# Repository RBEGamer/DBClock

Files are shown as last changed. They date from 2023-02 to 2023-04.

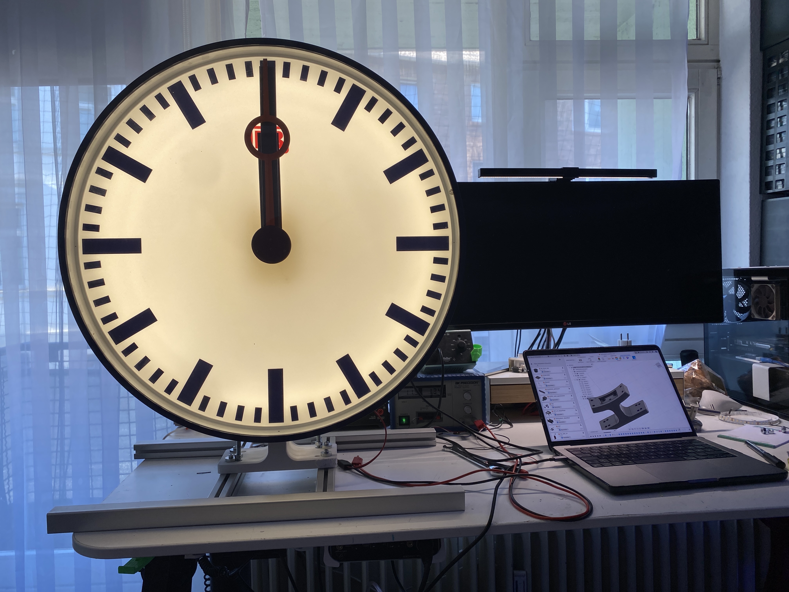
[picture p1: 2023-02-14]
documentation/images/2023-02-14 13.25.36.jpg

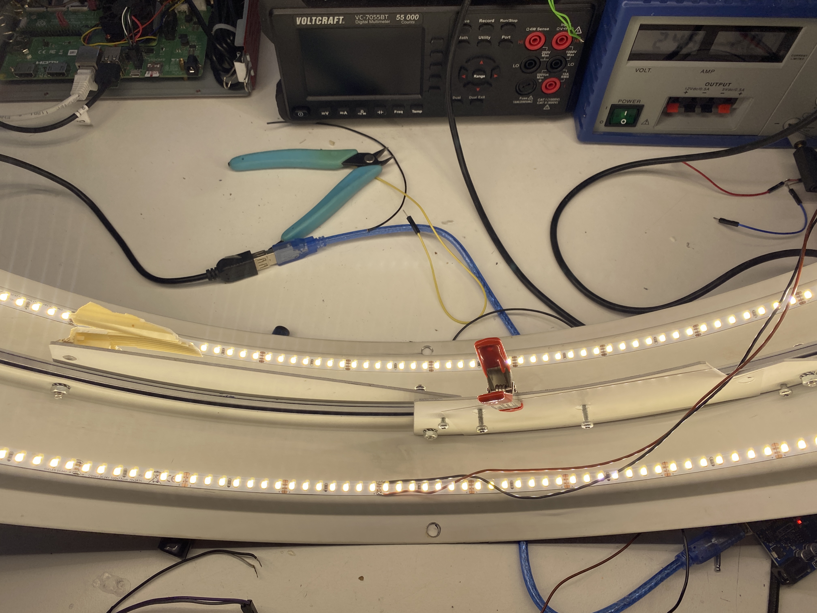
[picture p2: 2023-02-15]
documentation/images/2023-02-13 15.05.31.jpg

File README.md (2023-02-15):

# DBClock

final_clock

## Features

* NTP Sync
* LED lightning, dimmable
* Stand
* 12V 
* Webinterface for configuration
* Daylight Saving

## Bahnhofsuhr-DB

[bahnhofsuhr-db-shop](https://bahnshop.de/db-originale/sonstiges/1749/bahnhofsuhr-db)

Dark blue metal case, acrylic glass panes, dial white,with black hour and minute markers, red hole second hand, red DB logo unlit.

Condition: used, in new design, the sale is in the current condition as a decorative object, a function can not be guaranteed, rust spots, paint chips and scratches in the glass and paint are part of the character. The holder is not included in the delivery. The article picture is an exemplary representation.

Dimensions: 60 cm diameter
Weight: approx. 30 kg

Shipping is by freight forwarding on one-way pallet (free curbside). Disposal of the pallet is done by the customer.

In my clock, `BU 190t S230` the clock-drives were used.

### MORE LINKS

* [PROFILINE-Analoguhr.pdf]([https://bahnshop.de/db-originale/sonstiges/1749/bahnhofsuhr-db](https://www.mobatime.com/wp-content/uploads/2021/11/LD-800078.24-PROFILINE-Analoguhr.pdf))

## BU 190t S230

A complete manual for the drive can be found on the manufacturers website:
[Uhrwerk-BU-190-230-Installation.pdf](https://www.buerk-mobatime.de/wp-content/uploads/2020/01/BD-800603.01-Uhrwerk-BU-190-230-Installation.pdf)

### POWER THE DRIVE



I got the `BU 190t S230` version which needs 230v.
After a teardown, a small rectifier is found so that the drive uses a lower voltage for the motors and logic.
After further investigation on the transformers, the drive is internally operated with 12 V. 
So if you solder some wires directly to the rectifier and run it with a 12 V power supply, the drive works fine.
It also uses its own crystal, so no need for a stable 60Hz sync from the mains.

### SET THE TIME USING AN ARDUINO

In general it is simple to set the clock using a serial connection to the `IN` connector of the drive.
The connector is a `RJ12` jack it is connected to the Arduino using the following pins.

| Arduino | BU 190t | RJ12 pin |
|---|---|---|
| TX | TTL IN (RxD) | 1 |
| GND | GND | 2 |

The following Arduino code function sends the current time to the drive.
After running the code, the clockdrive syncs up.
This takes up the 6 minutes.

```c++
void send_time_to_clock(const uint8_t _h, const uint8_t _m, const uint8_t _s, bool _signal_ok = true);

void setup(){
  // NOTE THE SPEICAL SERIAL INIT ACCORDING THE DRIVES DATASHEET
  Serial.begin(9600,SERIAL_7E1);
}

void loop(){

send_time_to_clock(13,14,15)
//SEND THE CURRENT TIME EACH SECOND
// USE A DEDICATED TIMER FOR THIS
delay(1000); 
}
void send_time_to_clock(const uint8_t _h, const uint8_t _m, const uint8_t _s, bool _signal_ok = true){
  const uint8_t sec = max(_s, 60);
  String s = String(sec);
  if(sec<10){
    s="0"+s;
  }

  const uint8_t min = max(_m, 60);
  String m = String(min);
  if(min<10){
    m="0"+m;
  }

  const uint8_t hour = max(_h, 24);
  String h = String(hour);
  if(hour<10){
    h="0"+h;
  }

  String signok = "M";
  if(_signal_ok){
    signok = "A";
  }
  // USE WITH IN SETUP Serial.begin(9600,SERIAL_7E1);
  //DATE SET TO 10.10.2000 => NOT NEEDED HERE
  Serial.print("O" + signok + "L010100F"+ h + m + s +"\r");
}
```

In my case i used a Arduino Mega, with more than one hardware serial interface.
The desing is using `Serial2` for the clock drive and `Serial` to communicate with the PC or ESP8266 for NTP Sync.
By using a RTC like the `DS3231` in combination with the `ESP8266` for NTP sync, you get a very stable self syncing clock!
The the `src` directory for the Arduino and `ESP866` sources.

 Arduino

## LED

led

* [IRF520 MOSFET Treiber Modul](https://de.aliexpress.com/item/32667789271.html)
* [LED-Streifen 5m weiß](https://www.ledpoint.it/de/led-streifen-5m-warm-weiß-3500k-3step-2835-120ledm-12v-144wm)

The old lamp was replaced with a neutral-white 12B led strip with 144 LEDs/m.
Using a mosfet connected to the Arduino PWM GPIO `Pin 8`, so it is possible to control the strip using software.
The current implementation, allows fade up/down on predefined times, on/off from 0-100%.

### BUTTON

A pushbutton from `GND` to Arduino GPIO `2` can be connected to set the LED intensity modes manually.

## FINAL PINOUT

| Arduino | BU 190t RJ12 pin | DS3131 | PUSHBUTTON PIN | MOSFET PIN | ESP8266 |
|---|---|---|---|---|---|
| VIN | + pin on fullbridge | | | | |
| TX | TTL IN (RxD)  1 | | | | |
| GND | GND 2 | GND |  1 | GND | GND |
| 2 | | |  2 | | |
| 8 | | | | SIG | |
| 5V | | VCC | | VCC | VIN |
| RX | | | | | TX |
| SDA | | SDA | | | |
| SCL | | SCL | | | |

## Stand

stand

A clock stand/holder was not included, so a simple millable (or 3d printable ABS 100% infill) was designed.
The bottom holes are designed to be mounted on 30x30 n-nut profiles.
The files can be found in the `src/3d_print/clock_mount` directory.

Four `M8x30` with lock nuts were used to attach the clock to the milled stand.

**NOTE** The clock weighs about 30 kg, so the stand should be durable...

## PICTURES



### CLOCK FINGERS


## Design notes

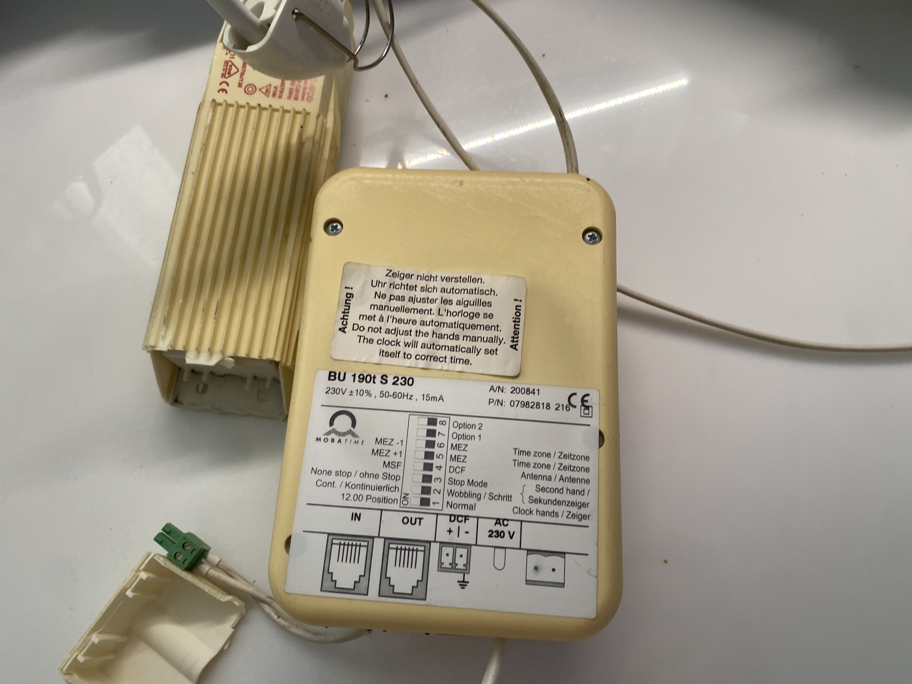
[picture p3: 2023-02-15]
documentation/images/2023-02-08 12.05.26.jpg

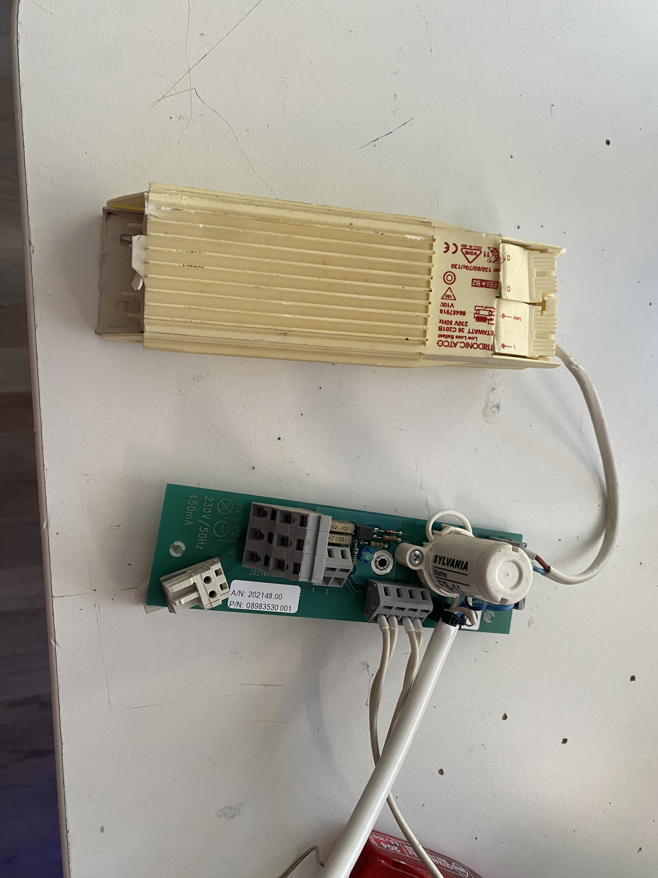
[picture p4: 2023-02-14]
documentation/images/2023-02-08 12.06.29.jpg

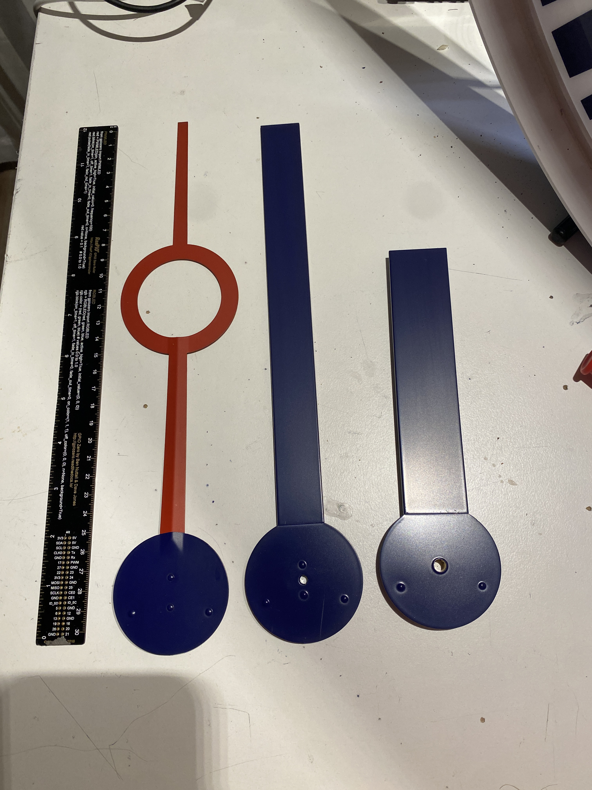
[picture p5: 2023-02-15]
documentation/images/2023-02-12 22.24.04.jpg

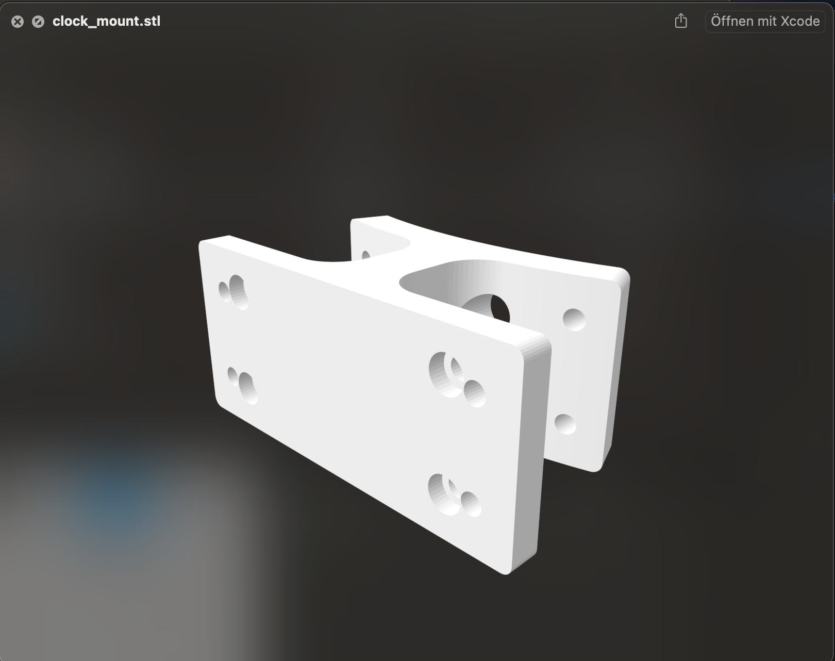
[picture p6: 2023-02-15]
documentation/images/stand.png

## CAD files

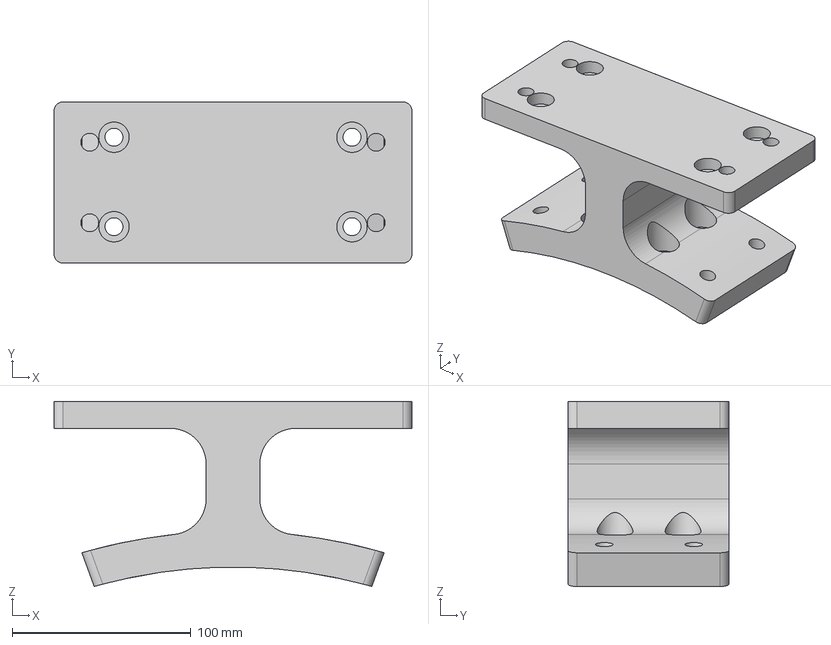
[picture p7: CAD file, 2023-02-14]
src/3d_print/clock_mount/clock_mount.step
200.0 x 90.0 x 103.4 mm

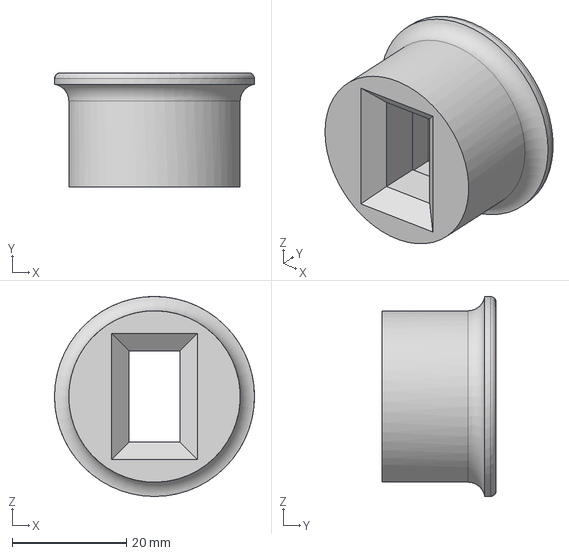
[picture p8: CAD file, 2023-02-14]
src/3d_print/usb_cable_mount/usb_cable_mount.step
35.0 x 20.0 x 35.0 mm

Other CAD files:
src/3d_print/clock_mount/clock_mount.f3d
src/3d_print/clock_mount/clock_mount.stl
src/3d_print/usb_cable_mount/usb_cable_mount.f3d
src/3d_print/usb_cable_mount/usb_cable_mount.stl

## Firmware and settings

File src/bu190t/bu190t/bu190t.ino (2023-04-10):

#define DS1307_CTRL_ID 0x68  //I2C ADDRESS OF DS3231 OR DS1307
#define EEPROM_INDEX_LED_MODE 0
#define EEPROM_INDEX_DLS 1
#define RTC_TIMEZONE 0 //0=UTC ,1=MEZ
#define VERSION "2.0.0"
#define WIFIEXTENTION_SERIAL Serial3 // TO ESP8266
#define CLOCK_SERIAL Serial2
#define DEBUG_SERIAL Serial //USB
#define LIGHTMODE_AUTO_HOUR_START 20
#define LIGHTMODE_AUTO_HOUR_END 23
#define LIGHTMODE_AUTO_HOUR_MAX_PWM 100

#include <EEPROM.h>
#include <Wire.h>
#include "RTClib.h"


void send_status(const String _command, const String _payload);
void update_according_led_mode(const uint8_t _led_mode);
void send_time_to_clock(const int _h, const int _m, const int _s, bool _signal_ok = true);
uint16_t crc16(const String _data, const uint16_t _poly = 0x8408);
bool check_for_i2c_device(const uint8_t _addr);
bool summertime_eu(const int _year, const signed char _month, const signed char _day, const signed char _hour);
String getValue(const String data, const char separator, const int index);

int clock_hour = 0;
int clock_min = 0;
int clock_sec = 0;

const uint8_t PIN_BUTTON_BRGHT = 2;
const uint8_t PIN_LED_PWM = 8;
const long CLOCK_UPDATE_INTERAL = 1000;


unsigned long previousMillis = 0;
uint8_t current_led_pwm = 0; // to fade from 0-255
uint8_t target_led_pwm = 0;
bool last_brght_button_state = false;


String readString;
bool cmd_started = false;
#define CMD_START_CHARACTER '%'
#define CMD_SEPERATION_CHARACTER '_'
//EEPROM MANAGED VARIABLES
uint8_t led_mode = 0;
uint8_t daylightsaving_enabled = 0;


RTC_DS1307 rtc;

void setup() {
  // put your setup code here, to run once:
  DEBUG_SERIAL.begin(9600);
  //IMPORTANT FOR THE BU 190t WATCH DRIVES
  CLOCK_SERIAL.begin(9600,SERIAL_7E1); // FIRST CLOCK DRIVE
  //FOR WIFI INTERFACE
  WIFIEXTENTION_SERIAL.begin(9600);
  // INIT PINS
  pinMode(PIN_BUTTON_BRGHT, INPUT_PULLUP);
  pinMode(PIN_LED_PWM, OUTPUT);
  analogWrite(PIN_LED_PWM, 0);

  //READ EEEPROM VALUES
  led_mode = EEPROM.read(EEPROM_INDEX_LED_MODE);
  daylightsaving_enabled = EEPROM.read(EEPROM_INDEX_DLS);

  update_according_led_mode(led_mode);
  //INIT I2C
  Wire.begin();
  //CHECK IF RTC IS PRESENT
  //SETUP TIME
  if(check_for_i2c_device(DS1307_CTRL_ID)){
    //CHECK IF RTC IS IN STOP MODE SO ONE INITIAL SET IS NEEDED
    // ITS NOT WORKING IF THE TIMLIB IS USED DIRECTLY
    if(rtc.begin()){
      if (!rtc.isrunning()) {
        Serial.println("RTC lost power, let's set the time!");
        rtc.adjust(DateTime(F(__DATE__), F(__TIME__)));
      }else{
        send_status("log", "RTC RUNNING");
        rtc.adjust(DateTime(F(__DATE__), F(__TIME__)));
      }
       
    }else{
      send_status("log", "!RtcChipPresent");
    }
    send_status("log", "RtcFound");
  }else{
    send_status("log", "RtcNotFound");
  }
  
  send_status("version", VERSION); 
  
}


String getValue(const String data, const char separator, const int index) {
  int found = 0;
  int strIndex[] = {
    0,
    -1
  };
  int maxIndex = data.length() - 1;
  for (int i = 0; i <= maxIndex && found <= index; i++) {
    if (data.charAt(i) == separator || i == maxIndex) {
      found++;
      strIndex[0] = strIndex[1] + 1;
      strIndex[1] = (i == maxIndex) ? i + 1 : i;
    }
  }
  return found > index ? data.substring(strIndex[0], strIndex[1]) : "";
}

void send_status(const String _command, const String _payload){
 DEBUG_SERIAL.println("%" + _command + "_" + _payload + "_" + crc16(_command + _payload));
 WIFIEXTENTION_SERIAL.println("%" + _command + "_" + _payload + "_" + crc16(_command + _payload));
}


bool check_for_i2c_device(const uint8_t _addr){
    Wire.beginTransmission(_addr);
    uint8_t error = Wire.endTransmission();
    if (error == 0) {
      return true;
    }
    return false;
}

// https://forum.arduino.cc/t/time-libary-sommerzeit-winterzeit/221884/2
// European Daylight Savings Time calculation by "jurs" for German Arduino Forum
// input parameters: "normal time" for year, month, day, hour and tzHours (0=UTC, 1=MEZ)
// return value: returns true during Daylight Saving Time, false otherwise
// #define RTC_TIMEZONE 0=UTC ,1=MEZ
bool summertime_eu(const int _year, const signed char _month, const signed char _day, const signed char _hour)
{
    if (_month < 3 || _month > 10)
    {
        return false; // keine Sommerzeit in Jan, Feb, Nov, Dez
    }
    else if (_month > 3 && _month < 10)
    {
        return true; // Sommerzeit in Apr, Mai, Jun, Jul, Aug, Sep
    }
    else if (_month == 3 && (_hour + 24 * _day) >= (1 + RTC_TIMEZONE + 24 * (31 - (5 * _year / 4 + 4) % 7)) || _month == 10 && (_hour + 24 * _day) < (1 + RTC_TIMEZONE + 24 * (31 - (5 * _year / 4 + 1) % 7)))
    {
        return true;
    }
    else
    {
        return false;
    }
}

uint16_t crc16(const String _data, const uint16_t _poly = 0x8408) {
  uint16_t crc = 0xFFFF;
  for (int i = 0; i < _data.length(); i++) {
    const uint8_t b = (byte)_data[i];
    uint8_t cur_byte = 0xFF & b;

    for (int it = 0; it < 8; it++) {
      if ((crc & 0x0001) ^ (cur_byte & 0x0001)) {
        crc = (crc >> 1) ^ _poly;
      } else {
        crc >>= 1;
      }
      cur_byte >>= 1;
    }
  }
  crc = (~crc & 0xFFFF);
  crc = (crc << 8) | ((crc >> 8) & 0xFF);
  return crc & 0xFFFF;
}


void send_time_to_clock(const int _h, const int _m, const int _s, bool _signal_ok = true){
  const int sec = _s%60;
  String s = String(sec);
  if(sec<10){
    s="0"+s;
  }

  const int min = _m%60;
  String m = String(min);
  if(min<10){
    m="0"+m;
  }

  const int hour = _h%24;
  String h = String(hour);
  if(hour<10){
    h="0"+h;
  }

  String signok = "M";
  if(_signal_ok){
    signok = "A";
  }
  // USE WITH Serial.begin(9600,SERIAL_7E1);
  CLOCK_SERIAL.print("O" + signok + "L230212F"+ h + m + s +"\r");
  //Serial3.print("O" + signok + "L230212F"+ h + m + s +"\r");
  send_status("ct", h + ":" + m + ":" + s);
}


void update_according_led_mode(const uint8_t _led_mode){
    const uint8_t led_mode = _led_mode % 7;
    if(led_mode == 0){
      target_led_pwm = 0;
    }else if(led_mode == 1){
      target_led_pwm = 20;
    }else if(led_mode == 2){
      target_led_pwm = 50;
    }else if(led_mode == 3){
      target_led_pwm = 150;
    }else if(led_mode == 4){
      target_led_pwm = 200;
    }else if(led_mode == 5){
      target_led_pwm = 255;  
     }else if(led_mode == 6){
       target_led_pwm = 0;
       current_led_pwm = 20;//INDICATE CLOCK IS IN AUTO
      //AUTO
    }
}
  

// SET TIME
//SET DATE
// SET DLS
// SET BRIGHNESS target_led_pwm




void loop() {

  
  

  /// BUTTOM FOR LIGHTMODE TOGGLE
  if(digitalRead(PIN_BUTTON_BRGHT) == LOW && last_brght_button_state == true){
    last_brght_button_state = false;
    led_mode++;
    if(led_mode > 6){
      led_mode = 0;
    }
    
    send_status("log", "LedMode" + String(led_mode));
    //SAVE LED MODE
    EEPROM.write(EEPROM_INDEX_LED_MODE,led_mode);
    update_according_led_mode(led_mode);

    
  }else if(digitalRead(PIN_BUTTON_BRGHT) == HIGH){
    last_brght_button_state = true;
  }


  // SEND TIME TO CLOCK EVERY 1s
  const unsigned long currentMillis = millis();
  if (currentMillis - previousMillis >= CLOCK_UPDATE_INTERAL) {
    previousMillis = currentMillis;
    DEBUG_SERIAL.println(".");
      DateTime now = rtc.now();
      int h = now.hour();
      if (daylightsaving_enabled > 0 && !summertime_eu(now.year(), now.month(), now.day(), h))
      {
        signed char h = h - 1;
        if (h < 0)
        {
            h += 24;
        }
        h = h % 24;
      }
      //SEND TIME TO CLOCK-DRIVES
      send_time_to_clock(h, now.minute(),now.second(), true);

      //ALSO HANDLE LED MODE AUTO
      if(led_mode == 6){
        // FADE 0-max and max-0
        //light up 3times as fast as for light down
        if(h == LIGHTMODE_AUTO_HOUR_START){
          target_led_pwm = map(max(now.minute()*3, 60),0,60,0, LIGHTMODE_AUTO_HOUR_MAX_PWM);
        }else if(h == LIGHTMODE_AUTO_HOUR_END){
          target_led_pwm = map(now.minute(),0,60,LIGHTMODE_AUTO_HOUR_MAX_PWM, 0);
        }
      }
    

    if(target_led_pwm != current_led_pwm){
      send_status("led", String(target_led_pwm));
    }
  }
  
  // UPDATE LEDS WITH SOME RAMP UP/DOWN
  if(target_led_pwm < current_led_pwm){
    if(abs(target_led_pwm-current_led_pwm) > 20){
      current_led_pwm-= 3;      
    }else{
      current_led_pwm--;
    } 
    analogWrite(PIN_LED_PWM, current_led_pwm);

  }else if(target_led_pwm > current_led_pwm){
    if(abs(target_led_pwm-current_led_pwm) > 20){
      current_led_pwm+= 3;
    }else{
      current_led_pwm++;
    }
    analogWrite(PIN_LED_PWM, current_led_pwm);
  }


    while (WIFIEXTENTION_SERIAL.available()) {
      delay(30); //delay to allow buffer to fill
      if (WIFIEXTENTION_SERIAL.available() > 0) {
        const char c = WIFIEXTENTION_SERIAL.read(); //gets one byte from serial buffer  
        
        if (c == '\n') {
          WIFIEXTENTION_SERIAL.flush();
          cmd_started = false;
          readString += CMD_SEPERATION_CHARACTER;
          break;
        }else if(c == CMD_START_CHARACTER && !cmd_started){
          cmd_started = true;
          readString = "";
        }else if(cmd_started){
          readString += c; //makes the string readString
        }         
      }
    }

    if (readString.length() > 0) {
      
      const String cmd = getValue(readString, CMD_SEPERATION_CHARACTER, 0);
      const String cmd_value = getValue(readString, CMD_SEPERATION_CHARACTER, 1);
      //st
      //sd
      if(cmd == "sb" && cmd_value != ""){
        const int tmp = cmd_value.toInt();
        if(tmp >= 0 && tmp < 7){
            led_mode = tmp;
            EEPROM.write(EEPROM_INDEX_LED_MODE,led_mode);
            update_according_led_mode(led_mode);
            DEBUG_SERIAL.println(led_mode);
        }
      }else if(cmd == "dls" && cmd_value != ""){
        const int dlsi = cmd_value.toInt();
        if(dlsi >= 0 && dlsi < 2){
          daylightsaving_enabled = dlsi;
          EEPROM.write(EEPROM_INDEX_DLS, daylightsaving_enabled);
        }
      }else if(cmd == "st" && cmd_value != ""){ //SET TIME
        const String sth = getValue(cmd_value, ':', 0);
        const String stm = getValue(cmd_value, ':', 1);
        const String sts =  getValue(getValue(cmd_value, ':', 2), '_', 0);;
        
        if(sth != "" && stm != ""){
          const int ih = sth.toInt();
          const int im = stm.toInt();
          const int is = sts.toInt();
          
          if(ih >0 && ih < 24 && im >0 && im < 60 && is >0 && is < 60){
            DateTime now = rtc.now();
            rtc.adjust(DateTime(now.year(), now.month(), now.day(), ih, im, is));
          }
        }
        DEBUG_SERIAL.println(sth + "::" + stm + "::" + sts);
      }else if(cmd == "sd" && cmd_value != ""){ //SET DATE
        const String sdday = getValue(cmd_value, '.', 0);
        const String sdmonth = getValue(cmd_value, '.', 1);
        const String sdyear = getValue(getValue(cmd_value, '.', 2), '_', 0);
        
        if(sdday != "" && sdmonth != "" && sdyear != ""){
          const int iday = sdday.toInt();
          const int imonth = sdmonth.toInt();
          const int iyear = sdyear.toInt();
          
          if(iday > 0 && iday < 31 && imonth >0 && imonth < 12){
            DateTime now = rtc.now();
            rtc.adjust(DateTime(iyear, imonth, iday, now.hour(), now.minute(), now.second()));
          }
        }
        DEBUG_SERIAL.println(sdday + ".." + sdmonth + ".." + sdyear);
      }

      send_status("gotcmd", cmd + "-"+cmd_value+"-");
      readString = "";
    } 

  delay(10);
}

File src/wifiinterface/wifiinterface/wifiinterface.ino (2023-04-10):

#define VERSION "3.2.1"
// ENABLE ON ESP8266-01 !!!!!!!!!!!!!!!!!!!!!!!!!!
#define USE_LITTLEFS
//FOR ESP8266-01
#define LED_BUILTIN 2

#include <Arduino.h>
#include "FS.h"

#ifdef ESP8266
#include <ESP8266WiFi.h>
#include <ESP8266WebServer.h>
#include <ESP8266mDNS.h>
#endif

#ifdef ESP32
#include <WebServer.h>
#define FORMAT_SPIFFS_IF_FAILED true
#ifdef USE_LITTLEFS
#define SPIFFS LITTLEFS
#include <LITTLEFS.h>
#else
#include <SPIFFS.h>
#endif
#include <ESPmDNS.h>
#endif



#include <WiFiClient.h>
#include <WiFiUdp.h>
#include <TimeLib.h>
#include <NTPClient.h>
#include <WiFiManager.h>
#include <WiFiUdp.h>
#include <ArduinoOTA.h>


// CONFIG -------------------------------------
#define WEBSERVER_PORT 80                                     // set the port for the webserver eg 80 8080
#define MDNS_NAME "dbclock"                                 // set hostname
#define WEBSITE_TITLE "DB Wifi Module Configuration"  // name your device
#define SERIAL_BAUD_RATE 9600
#define NTP_SEND_TIME_INTERVAL 60*60  //sende zeit an uhr all x minuten
#define DEFAULT_NTP_SERVER "pool.ntp.org"
#define DEFAULT_TIMEZONE 1
// END CONFIG ---------------------------------




String time_last = "not synced";
long last = 0;
long last_ee = 0;
#if defined(ESP8266)
const String BOARD_INFO = "DBCLOCKWIFIMODULE_FW_" + String(VERSION) + "_BOARD_" + "ESP8266";
#elif defined(ESP32)
const String BOARD_INFO = "DBCLOCKWIFIMODULE_FW_" + String(VERSION) + "_BOARD_" + "ESP32";
#endif
bool ntp_force_update = true;

const String ap_name = "DBClockConfiguration";

// END NEOPIXEL CONF ---------------------------
//FILES FOR STORiNG CONFIGURATION DATA
const char* file_ntp_server = "/file.txt";
const char* file_timezone = "/timezone.txt";
//VARS

int timezone = 0;
String ntp_server_url = "pool.ntp.org";
String last_error = "";
int rtc_hours = 0;
int rtc_mins = 0;
int rtc_secs = 0;
int rtc_day = 1;
int rtc_month = 1;
int rtc_year = 2020;
int rtc_hours_tmp = 0;
//IS SET TO TRUE IN SETUP IF A RTC CLOCK IS DETECTED
//USEDE FOR SOFTWARE CLOCK
unsigned long timeNow = 0;
unsigned long timeLast = 0;


// INSTANCES --------------------------------------------

#ifdef ESP8266
ESP8266WebServer server(WEBSERVER_PORT);
#endif

#ifdef ESP32
WebServer server(WEBSERVER_PORT);
#endif

WiFiUDP ntpUDP;
NTPClient timeClient(ntpUDP, DEFAULT_NTP_SERVER, 0, 60000);
WiFiClient espClient;
WiFiManager wifiManager;






const String phead_1 = "<!DOCTYPE html><html><head><title>";
const String phead_2 = "</title>"
                       "<meta http-equiv='content-type' content='text/html; charset=utf-8'>"
                       "<meta charset='utf-8'>"
                       "<link "
                       "href='http://ajax.googleapis.com/ajax/libs/jqueryui/1.8.16/themes/base/"
                       "jquery-ui.css' rel=stylesheet />"
                       "<script "
                       "src='http://ajax.googleapis.com/ajax/libs/jquery/1.6.4/jquery.min.js'></"
                       "script>"
                       "<script "
                       "src='http://ajax.googleapis.com/ajax/libs/jqueryui/1.8.16/"
                       "jquery-ui.min.js'></script>"
                       "<style>"
                       "html, body {"
                       "  background: #F2F2F2;"
                       " width: 100%;"
                       " height: 100%;"
                       " margin: 0px;"
                       " padding: 0px;"
                       " font-family: 'Verdana';"
                       " font-size: 16px;"
                       " color: #404040;"
                       " }"
                       "img {"
                       " border: 0px;"
                       "}"
                       "span.title {"
                       " display: block;"
                       " color: #000000;"
                       " font-size: 30px;"
                       "}"
                       "span.subtitle {"
                       " display: block;"
                       " color: #000000;"
                       " font-size: 20px;"
                       "}"
                       ".sidebar {"
                       " background: #FFFFFF;"
                       " width: 250px;"
                       " min-height: 100%;"
                       " height: 100%;"
                       " height: auto;"
                       " position: fixed;"
                       " top: 0px;"
                       " left: 0px;"
                       " border-right: 1px solid #D8D8D8;"
                       "}"
                       ".logo {"
                       " padding: 25px;"
                       " text-align: center;"
                       " border-bottom: 1px solid #D8D8D8;"
                       "}"
                       ".menu {"
                       " padding: 25px 0px 25px 0px;"
                       " border-bottom: 1px solid #D8D8D8;"
                       "}"
                       ".menu a {"
                       " padding: 15px 25px 15px 25px;"
                       " display: block;"
                       " color: #000000;"
                       " text-decoration: none;"
                       " transition: all 0.25s;"
                       "}"
                       ".menu a:hover {"
                       " background: #0088CC;"
                       " color: #FFFFFF;"
                       "}"
                       ".right {"
                       " margin-left: 250px;"
                       " padding: 50px;"
                       "}"
                       ".content {"
                       " background: #FFFFFF;"
                       " padding: 25px;"
                       " border-radius: 5px;"
                       " border: 1px solid #D8D8D8;"
                       "}"
                       "</style>";

const String pstart = "</head>"
                      "<body style='font-size:62.5%;'>"
                      "<div class='sidebar'>"
                      "<div class='logo'>"
                      "<span class='title'>WordClock - WIFI MODULE</span>"
                      "<span class='subtitle'>- Configuration -</span>"
                      "</div>"
                      "<div class='menu'>"
                      "<a href='index.html'>Settings</a>"
                      "</div>"
                      "</div>"
                      "<div class='right'>"
                      "<div class='content'>";

const String pend = "</div></div></body></html>";





uint16_t crc16(String _data, uint16_t _poly = 0x8408) {
  uint16_t crc = 0xFFFF;
  for (int i = 0; i < _data.length(); i++) {
    const uint8_t b = (byte)_data[i];
    uint8_t cur_byte = 0xFF & b;

    for (int it = 0; it < 8; it++) {
      if ((crc & 0x0001) ^ (cur_byte & 0x0001)) {
        crc = (crc >> 1) ^ _poly;
      } else {
        crc >>= 1;
      }
      cur_byte >>= 1;
    }
  }
  crc = (~crc & 0xFFFF);
  crc = (crc << 8) | ((crc >> 8) & 0xFF);
  return crc & 0xFFFF;
}
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

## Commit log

2023-04-10 replace timelib with normal rtc lib
    [bu190t.ino, wifiinterface.ino]
2026-10-29 Add Pico W + W5100S network interface, fix Mega bugs, move to PlatformIO
    Pico W network interface (src/picowinterface):
    - WiFi (CYW43) and LAN (WIZnet Ethernet HAT, W5100S) at the same time,
    LAN preferred, same serial protocol to the Mega as the ESP8266 module
    - captive portal access point replaces WiFiManager, WiFi settings on
    the webinterface, browser firmware update on /update, watchdog
    Mega fixes (src/bu190t):
    - accept 0 for hour/minute/second and the 31st / December in st/sd
    - daylight saving was never applied (shadowed variable); RTC now runs
    on standard time and one hour is added during EU summer time
    - do not reset the RTC to the compile time on every boot
    - LED: perceived bri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
2026-10-29 Pico: detect WiFi chip and Ethernet HAT at boot, add Pico 2 builds
    - network mode is selected from the detected hardware: LAN (+ WiFi if
    configured), WiFi only without HAT, LAN only on boards without WiFi
    - all WiFi calls are skipped on a Pico without CYW43; the rpipicow build
    runs on Pico and Pico W, new envs rpipico2w and rpipico2
    - fix: in AP mode WiFi.status() reports WL_CONNECTED, so "(IP unset)" was
    sent to the clock; wait for the AP IP before starting the captive DNS
    - boot log waits for USB serial and prints board and network mode
    - tested on a Pico W without HAT: WIFI ONLY, access point on 192.168.4.1
2026-10-29 Pico: no error for unsaved settings files, fix DISABLED typo
    Tested on Pico W + WIZnet Ethernet HAT: LAN+WIFI mode, DHCP lease,
    NTP sync sent to the clock, webinterface and /update reachable.
2026-10-29 Millisecond time sync to the clock, faster Mega UART reader, mobile web page
    Pico (4.2.0):
    - own SNTP request with microsecond resolution and network delay
    compensation, replaces NTPClient (full seconds only)
    - the time frame is sent right before a full second so its last byte
    arrives at the second; measured within a few ms of NTP time, before
    0 to 1 s behind
    - zero padded time and date, clear error if the NTP server can not be
    resolved
    - new mobile friendly webinterface: cards, dark mode, live clock, light
    buttons, active connection in the header, confirmation messages
    Mega (2.2.0):
    - serial reader without 30 ms per byte delay, commands are processed
    only after the complete lin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
2026-10-29 Home Assistant integration and REST API for the light
    Pico (4.3.0):
    - MQTT with Home Assistant discovery: dimmable light (1-100 %, effect
    Auto) and a Sync time button, availability via last will, broker
    settings on the webinterface, reconnect with backoff 15 s to 5 min
    - REST API: /api/light (state, brightness, mode) and /api/status
    - reads the optional feedback line from the Mega (TX3 -> GP1 via voltage
    divider), CRC checked, confirms the light state and shows the clock link
    - web page: brightness slider, light state, Home Assistant card
    - PubSubClient 2.8 vendored in lib/
    Mega (2.3.0):
    - sl_<0-100> sets a manual brightness (mode 7, stored in the EEPROM),
    sb_7 restores it
    - %ls_<mo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
2026-10-29 Settable MQTT base topic and Send discovery button
    - Base topic field on the webinterface, stored in /mqtt_topic.txt, empty = dbclock/<id>
    - On a change the retained messages below the old topic are removed and the discovery is sent with the new topics
    - Send discovery button, /api/status reports the base topic
    - Pico firmware 4.4.0
2026-10-29 Up to 3 NTP servers: primary and 2 fallbacks
    - Fallback NTP server fields in the Clock section, stored in /ntp_server2.txt and /ntp_server3.txt, empty = off
    - Defaults pool.ntp.org, time.cloudflare.com, ptbtime1.ptb.de, tried in this order until one answers
    - 2 s dns timeout per server and watchdog reset in between
    - Page, last message and /api/status (ntp_host) show the server of the last sync
    - Pico firmware 4.5.0
2026-10-29 Reliable WiFi recovery on the Pico
    - WiFi counts as connected only with a real CYW43 link, the core keeps the IP after a drop, so the module never reconnected
    - Setup access point runs together with the station (AP+STA) when credentials are stored, the WiFi is retried every 30 s and the access point closes on connect
    - Close the access point with disconnectAP(), softAPdisconnect() dropped the station or kept the access point
    - Give the default route to the WiFi station if LAN is not connected, after the access point it pointed nowhere and NTP failed
    - Watchdog starts before the WiFi setup, joins are limited to 5 s and retried during boot
    - Network status line on the USB serial every 30 s
    - P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
2026-10-29 Home Assistant light controls, diagnostics and daylight saving
    - Pico 4.7.0: Brightness slider (number) and Light mode select next to the light entity
    - Daylight saving switch and diagnostic sensors: NTP server, last sync, NTP delay, timezone, daylight saving state, clock time, connection, IP, WiFi signal, uptime (JSON on <base>/diag, every 60 s)
    - Web update (/update) resets the watchdog for every written block, slow uploads were aborted by the watchdog
    - Webinterface shows the daylight saving state
    - Mega 2.4.0: reports %ds_<enabled>,<summer time> with the light state and after a dls command
2026-10-29 Docker firmware build for GitHub, Gitea and GitLab
    - ci/Dockerfile builds all Pico (rpipicow, rpipico2w, rpipico2) and Mega variants, toolchains in a cached layer
    - ci/docker_build.sh copies the files to dist/ with docker create + cp, works with Docker-in-Docker and act runners
    - Pipelines: .github/workflows, .gitea/workflows, .gitlab-ci.yml, artifact dbclock-firmware-<commit>, GitHub release on v* tags
    - Output: .uf2 and .bin per Pico variant, Mega .hex, SHA256SUMS, BUILDINFO.txt
    - README: prebuilt firmware, new Home Assistant entities and topics
